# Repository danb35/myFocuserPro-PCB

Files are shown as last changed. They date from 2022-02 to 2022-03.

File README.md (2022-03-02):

# myFocuserPro-PCB
 KiCad schematic and board for myFocuserPro2: https://sourceforge.net/projects/arduinofocuscontrollerpro/

# Introduction
myFocuserPro is a DIY, Arduino-based focuser designed for use with telescopes.  The design, source code, schematics, PCB files (Gerbers), and extensive documentation are available at the link above.  So what am I doing in this repo?

Unfortunately, the Gerbers there have a few issues, most notably that the footprint for the reverse-polarity protection diode (D1 on the schematic) just doesn't fit the specified diode.  The specified "fix" for the problem is to file down the leads of the diode until they fit through the holes.  And while this should be a trivial thing to fix, editable source files for the schematic and board haven't been released.

To address this, I re-drew the schematic and PCB layout in KiCad 6.0.  [KiCad](https://www.kicad.org/) is free, open source electronics design software, so you can download it to edit these files as desired.

# Design changes
This schematic is identical to the M-MT-F-BT DRV8825-HW203 variation at SourceForge, as that's the recommended version for new builds.  I intend (and hope) that the schematic will be easier to read and follow, but there should not be any changes in the components or how they're connected.  I don't intend to do this for any other variations of the schematic.  Most of the reference designators (i.e., R3, C2, etc.) are identical, but KiCad has changed some of the semiconductors.  But I've made a few changes to the board layout.

First, of course, there's the change that drove the whole redesign--the footprint for D1 now actually fits the specified diode.  I've also replaced most of the places where pin headers had been used for off-board connections (e.g., for the stepper, the pushbuttons, the display, etc.) and replaced them with JST-XH connectors.  These provide some friction to prevent connections from coming loose inadvertently, and also polarize the connections (so, e.g., you can't plug in a LED backward).  The only exception to this is J3, the programming "switch."  I intend that this will be a jumper, not an externally accessible switch.

While the board size is similar to the original, it is not identical, and it will not fit in the 3D-printed case design that's posted on SourceForge.  As time permits, I'll try to prepare a case design that will work with this.

# Board Images
Here are images of the front and back of the board:
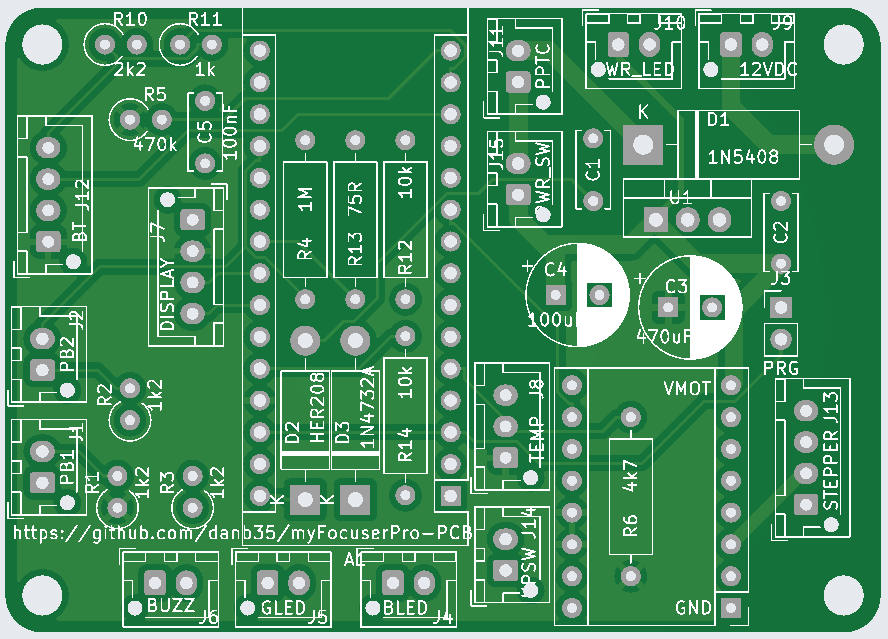
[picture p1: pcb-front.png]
PCB front side

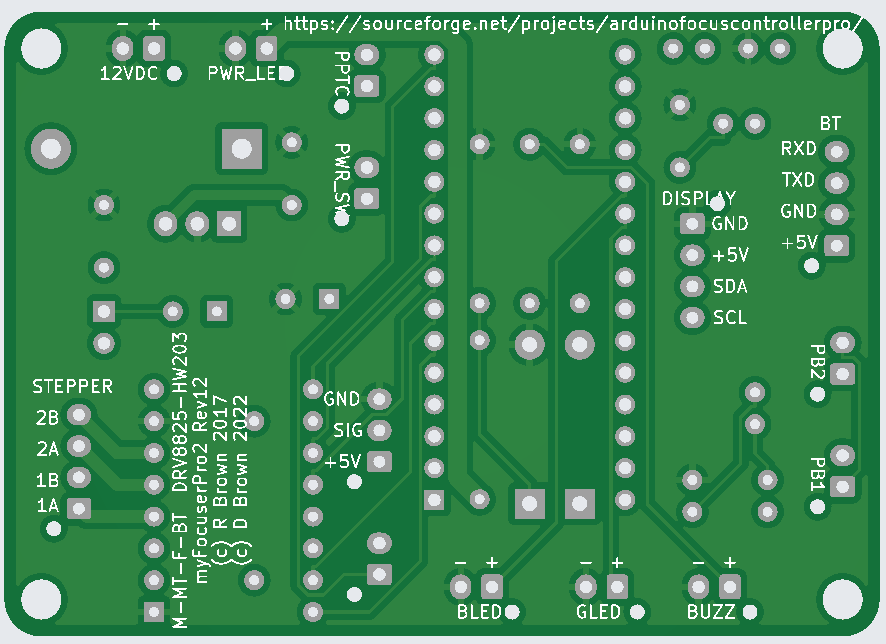
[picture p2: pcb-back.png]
PCB back side


And here are 3D renders of (mostly) populated boards:
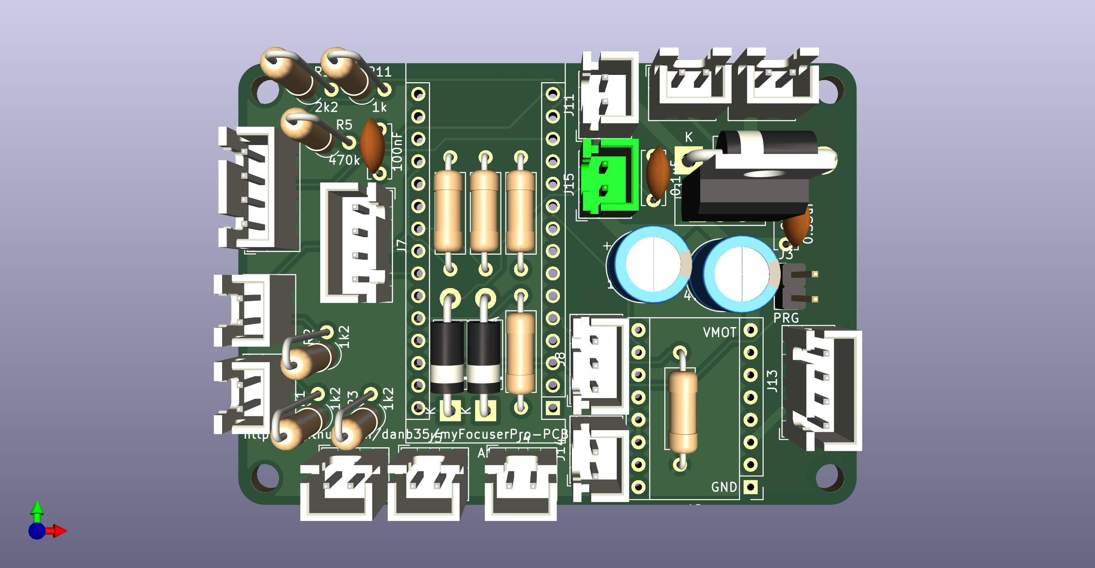
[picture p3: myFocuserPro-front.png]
Front PCB render

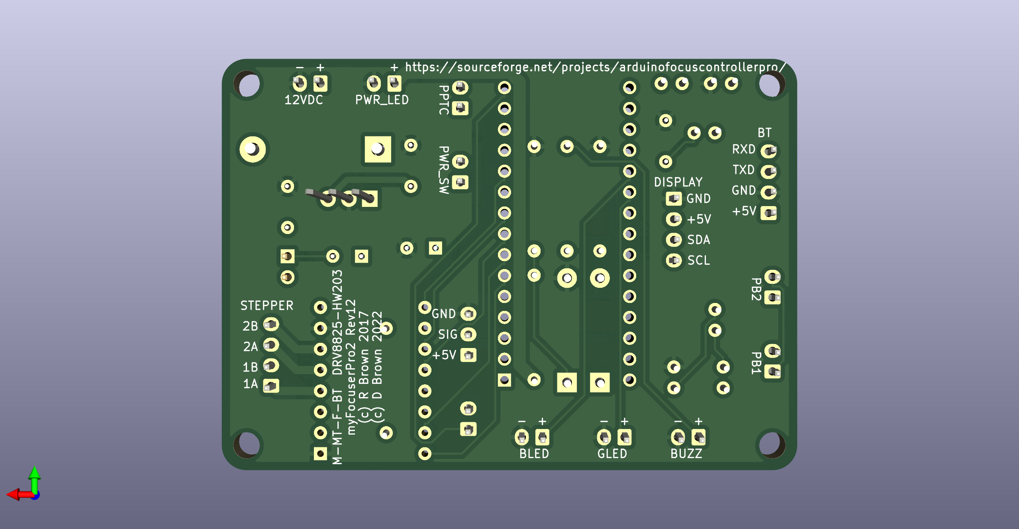
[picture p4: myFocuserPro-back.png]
Back PCB render


# Ordering
I don't sell these boards; you can have them made by any PCB fab you choose.  To do so, simply download Gerber/myFocuserPro.zip from this repo, upload it to your fab of choice, and have at it.  If you don't have a fab of choice, consider the two linked below, in which I have no financial interest (i.e., I'm not an affiliate, partner, or anything else; I don't make anything from your purchase of these boards--I'm just a customer of both services).

## OSHPark
OSHPark are an American company known for high-quality boards.  They'll produce three copies of your design for $5 per square inch, in purple, with gold plating.  This cost is often higher than the Chinese fabs, but they don't charge shipping, and you don't have to wait for shipping for China.  This board costs about $27 shipped for three copies as of this writing.  You can order boards using this link:
https://oshpark.com/profiles/danb35

## JLCPCB
[JLCPCB](https://jlcpcb.com/) are a Chinese PCB fab that I've been pretty happy with.  Their prices are low (starting at $2/5 boards), they produce the boards quickly, and they ship quickly via DHL.  The biggest drawback is the cost of shipping--at this writing, five boards will cost you $2, but the shipping is another $20 or more.

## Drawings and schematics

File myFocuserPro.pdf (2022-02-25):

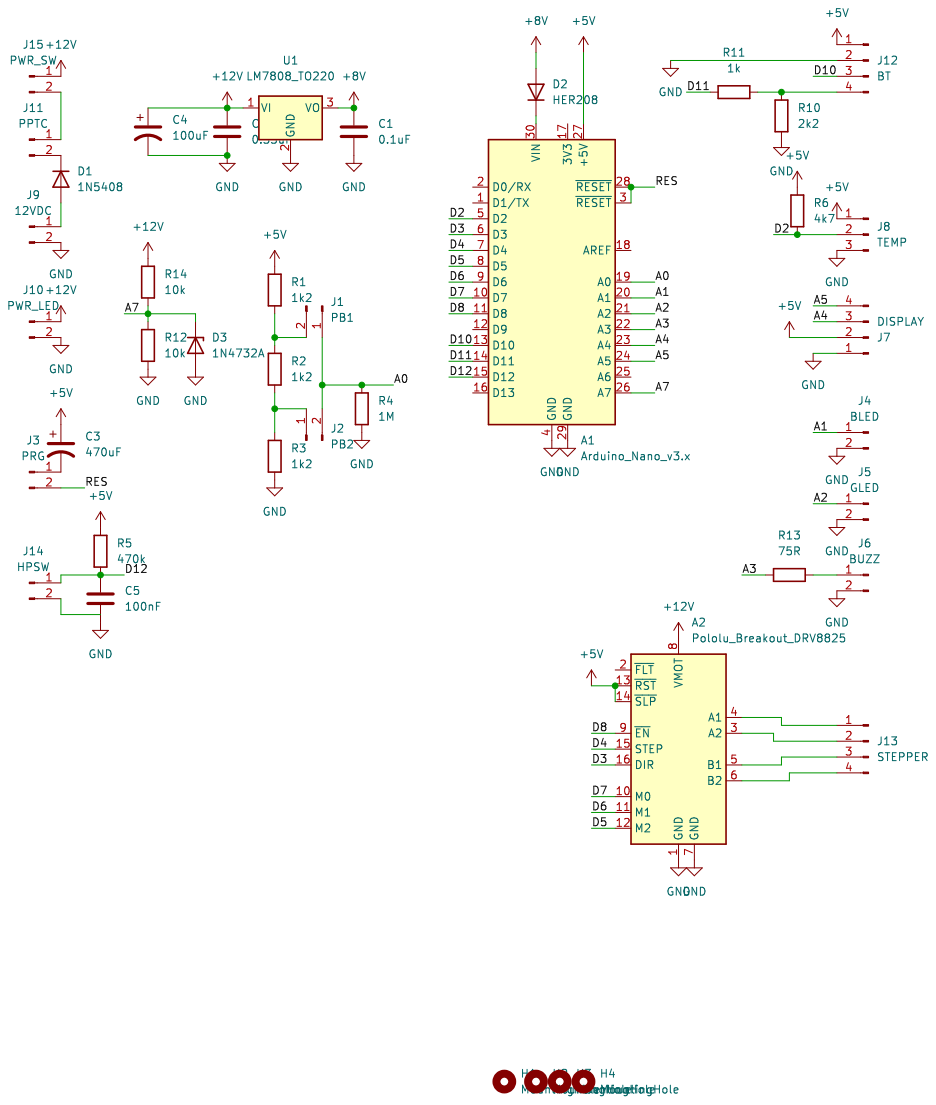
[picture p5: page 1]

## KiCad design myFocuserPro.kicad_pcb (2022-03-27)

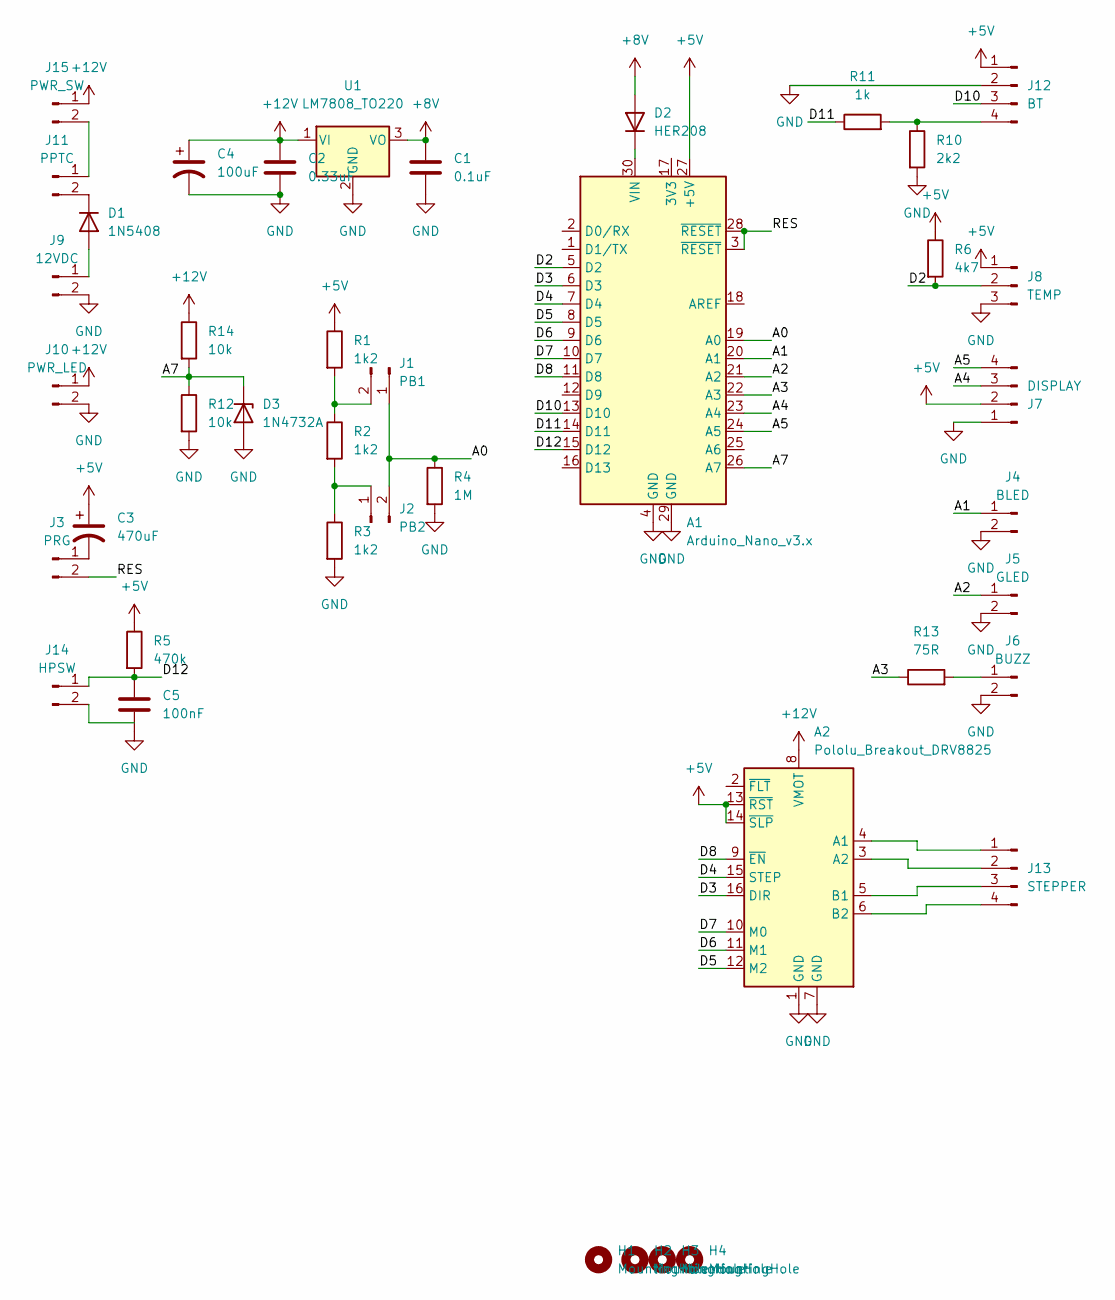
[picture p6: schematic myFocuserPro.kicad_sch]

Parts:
A1: Arduino_Nano_v3.x; Arduino_Nano
A2: Pololu_Breakout_DRV8825; Pololu_Breakout-16_15.2x20.3mm
C1: 0.1uF; C_Disc_D6.0mm_W2.5mm_P5.00mm
C2: 0.33uF; C_Disc_D6.0mm_W2.5mm_P5.00mm
C3: 470uF; CP_Radial_D8.0mm_P3.50mm
C4: 100uF; CP_Radial_D8.0mm_P3.50mm
C5: 100nF; C_Disc_D6.0mm_W2.5mm_P5.00mm
D1: 1N5408; D_DO-201AD_P15.24mm_Horizontal
D2: HER208; D_DO-15_P12.70mm_Horizontal
D3: 1N4732A; D_DO-15_P12.70mm_Horizontal
H1, H2, H3, H4: MountingHole; MountingHole_3.2mm_M3
J1: PB1; JST_XH_B2B-XH-AM_1x02_P2.50mm_Vertical
J2: PB2; JST_XH_B2B-XH-AM_1x02_P2.50mm_Vertical
J3: PRG; PinHeader_1x02_P2.54mm_Vertical
J4: BLED; JST_XH_B2B-XH-AM_1x02_P2.50mm_Vertical
J5: GLED; JST_XH_B2B-XH-AM_1x02_P2.50mm_Vertical
J6: BUZZ; JST_XH_B2B-XH-AM_1x02_P2.50mm_Vertical
J7: DISPLAY; JST_XH_B4B-XH-AM_1x04_P2.50mm_Vertical
J8: TEMP; JST_XH_B3B-XH-AM_1x03_P2.50mm_Vertical
J9: 12VDC; JST_XH_B2B-XH-AM_1x02_P2.50mm_Vertical
J10: PWR_LED; JST_XH_B2B-XH-AM_1x02_P2.50mm_Vertical
J11: PPTC; JST_XH_B2B-XH-AM_1x02_P2.50mm_Vertical
J12: BT; JST_XH_B4B-XH-AM_1x04_P2.50mm_Vertical
J13: STEPPER; JST_XH_B4B-XH-AM_1x04_P2.50mm_Vertical
J14: HPSW; JST_XH_B2B-XH-AM_1x02_P2.50mm_Vertical
J15: PWR_SW; JST_XH_B2B-XH-AM_1x02_P2.50mm_Vertical
R1, R2, R3: 1k2; R_Axial_DIN0309_L9.0mm_D3.2mm_P2.54mm_Vertical
R4: 1M; R_Axial_DIN0309_L9.0mm_D3.2mm_P12.70mm_Horizontal
R5: 470k; R_Axial_DIN0309_L9.0mm_D3.2mm_P2.54mm_Vertical
R6: 4k7; R_Axial_DIN0309_L9.0mm_D3.2mm_P12.70mm_Horizontal
R10: 2k2; R_Axial_DIN0309_L9.0mm_D3.2mm_P2.54mm_Vertical
R11: 1k; R_Axial_DIN0309_L9.0mm_D3.2mm_P2.54mm_Vertical
R12, R14: 10k; R_Axial_DIN0309_L9.0mm_D3.2mm_P12.70mm_Horizontal
R13: 75R; R_Axial_DIN0309_L9.0mm_D3.2mm_P12.70mm_Horizontal
U1: LM7808_TO220; TO-220-3_Vertical

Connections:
+5V: A1.27 (+5V), A2.13 (~RST), A2.14 (~SLP), C3.1, J7.2, J8.1, J12.1, R1.1, R5.1, R6.1
+8V: C1.1, D2.2 (A), U1.3 (VO)
+12V: A2.8 (VMOT), C2.1, C4.1, J10.1, J15.1, R14.1, U1.1 (VI)
/A0: A1.19 (A0), J1.1, J2.2, R4.1
/A1: A1.20 (A1), J4.1
/A2: A1.21 (A2), J5.1
/A3: A1.22 (A3), R13.1
/A4: A1.23 (A4), J7.3
/A5: A1.24 (A5), J7.4
/A7: A1.26 (A7), D3.1 (K), R12.1, R14.2
/D2: A1.5 (D2), J8.2, R6.2
/D3: A1.6 (D3), A2.16 (DIR)
/D4: A1.7 (D4), A2.15 (STEP)
/D5: A1.8 (D5), A2.12 (M2)
/D6: A1.9 (D6), A2.11 (M1)
/D7: A1.10 (D7), A2.10 (M0)
/D8: A1.11 (D8), A2.9 (~EN)
/D10: A1.13 (D10), J12.3
/D11: A1.14 (D11), R11.1
/D12: A1.15 (D12), C5.1, J14.1, R5.2
/RES: A1.3 (~RESET), A1.28 (~RESET), J3.2
GND: A1.4 (GND), A1.29 (GND), A2.1 (GND), A2.7 (GND), C1.2, C2.2, C4.2, C5.2, D3.2 (A), J4.2, J5.2, J6.2, J7.1, J8.3, J9.2, J10.2, J12.2, R3.2, R4.2, R10.2, R12.2, U1.2 (GND)
unnamed: A1.30 (VIN), D2.1 (K)
unnamed: A2.3 (A2), J13.2
unnamed: A2.4 (A1), J13.1
unnamed: A2.5 (B1), J13.3
unnamed: A2.6 (B2), J13.4
unnamed: C3.2, J3.1
unnamed: D1.1 (K), J11.2
unnamed: D1.2 (A), J9.1
unnamed: J1.2, R1.2, R2.1
unnamed: J2.1, R2.2, R3.1
unnamed: J6.1, R13.2
unnamed: J11.1, J15.2
unnamed: J12.4, R10.1, R11.2

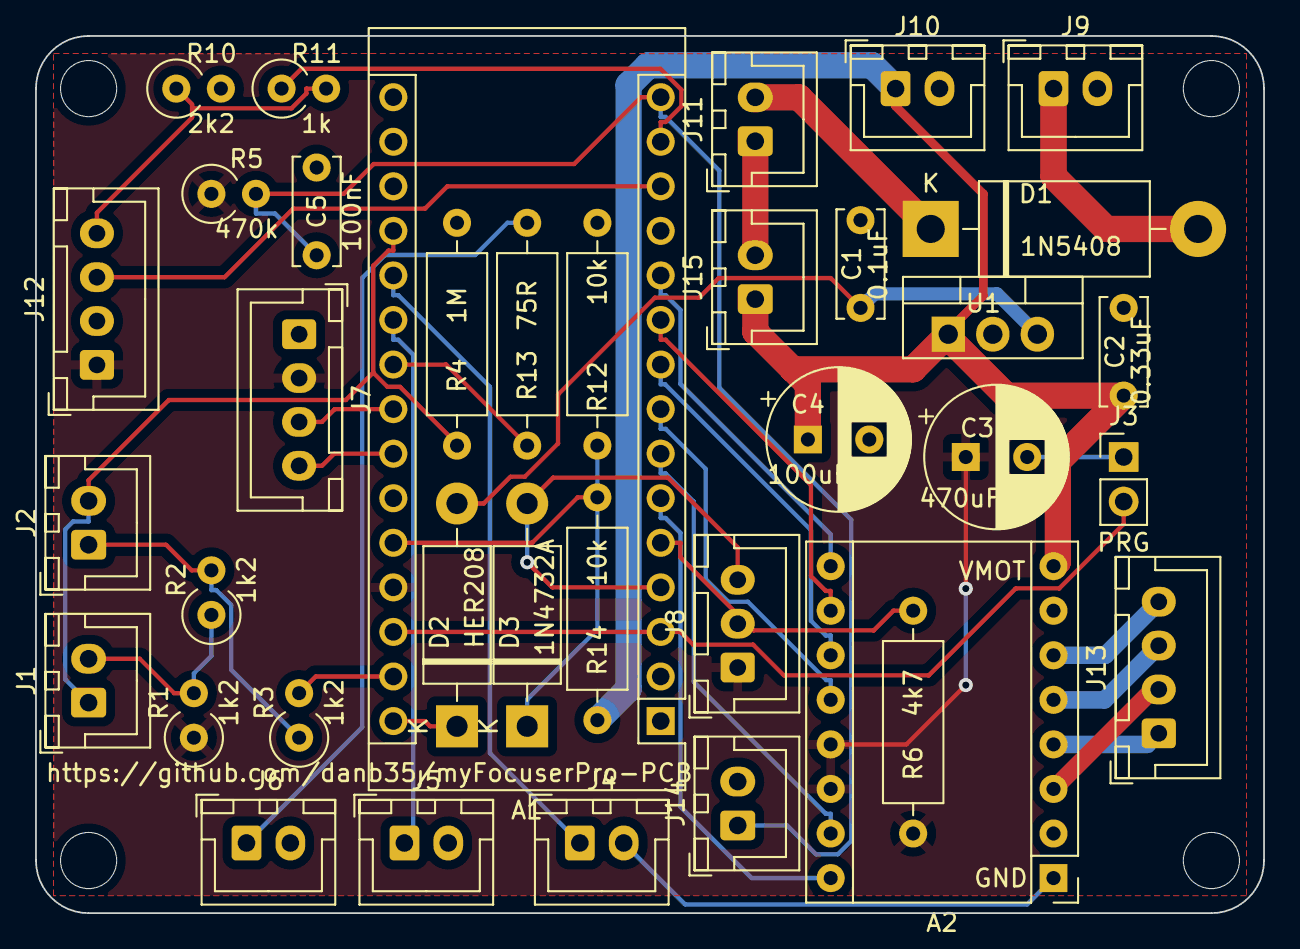
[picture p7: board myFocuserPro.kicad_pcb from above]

Board: 2 copper layers, 70.0 x 50.0 mm, 41 parts (0 on the bottom side), 35 nets.

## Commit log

2022-03-02 Update JST footprints
    [myFocuserPro.kicad_pcb]
2022-03-20 Connect isolated grounds
    [myFocuserPro.kicad_pcb]
2022-03-27 Update PCB layout
    [myFocuserPro.kicad_pcb]
